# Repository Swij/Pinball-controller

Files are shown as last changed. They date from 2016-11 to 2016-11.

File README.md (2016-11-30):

# Pinball-controller
## Repository structure
* __controller-PCB__ - The kicad PCB design for the controller board.
* __src__ - LUA source code to be run with NodeMcu on the ESP8266.

## Todo
#### PCB-design
* Calculate more precise values for transistor resistors.
* New design for Stern pinball machines.
* Find better solution for I/O shortage on ESP12-E.
* Minified design for factory manufacturing.

#### Firmware
* Make decision on which OS to use on ESP8266. NodeMcu, FreeRTOS, IoTcore etc.
* Communication method/protocol with server.
* Menu traversing method.

#### Master server
* Decide on which language to use. NodeJS, Python, PHP etc.
* Master server locally on for example Raspberry PI or on the internet with a VPS.

#### Payment solution
* Evaluate Swish API.
* Look at other payment solutions such as Strip, Paypal, Braintree etc.
* Decide if we should have an account balance system or only direct payments.

## Ideas
* RFID/NFC reader mounted at the coin machine. Swipe card/tag/phone to pay from balance.

## Kicad dependencies
To view the design in Kicad you need [kicad-ESP8266](https://github.com/jdunmire/kicad-ESP8266) and [Walters kicad libraries](http://smisioto.no-ip.org/elettronica/kicad/kicad-en.htm)

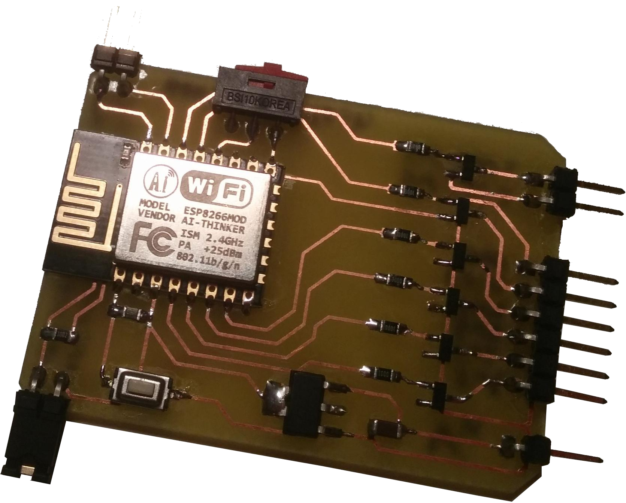
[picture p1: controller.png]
Handmade controller


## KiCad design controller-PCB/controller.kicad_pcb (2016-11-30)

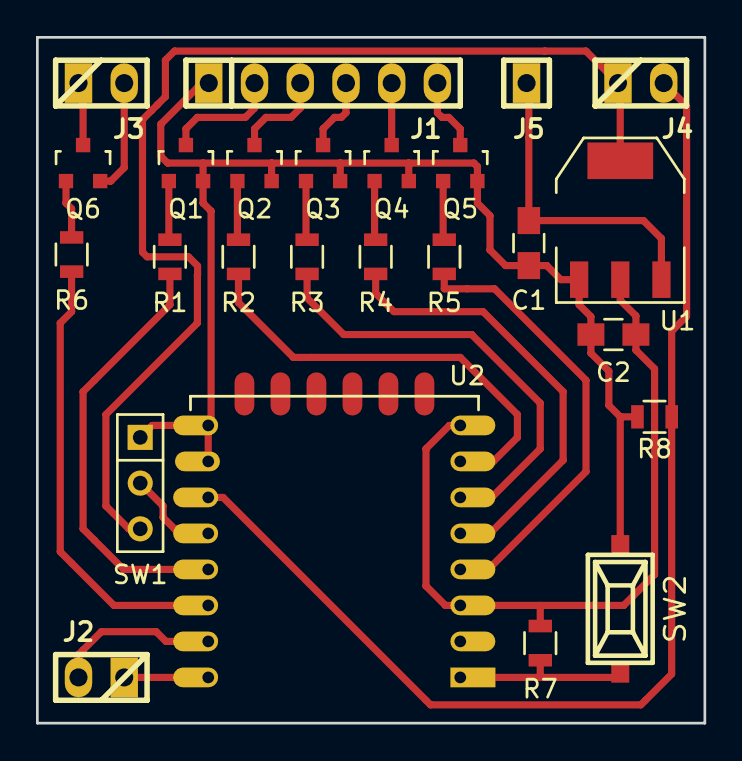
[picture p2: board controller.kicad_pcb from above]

Board: 2 copper layers, 37.1 x 38.1 mm, 25 parts (0 on the bottom side), 27 nets.

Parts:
C1, C2: 10uF; C_0805_HandSoldering
J1: Pinball I/O; pin_strip_6
J2: UART; pin_strip_2
J3: DOOR-IO; pin_strip_2
J4: DOOR-SW; pin_strip_2
J5: 12V; pin_strip_1
Q1, Q2, Q3, Q4, Q5, Q6: NPN_BEC; SOT-23
R1, R2, R3, R4, R5, R6: 1kΩ; R_0805
R7, R8: 10kΩ; R_0805
SW1: FLASH; SW_Micro_SPST
SW2: smd_push
U1: LM1117-3.3; SOT-223
U2: ESP-12E

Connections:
+12V: C1.1, J5.1, U1.3
/COIN: J1.2, Q1.3
/Pinball-SW1: J1.6, Q5.3
/Pinball-SW2: J1.5, Q4.3
/Pinball-SW3: J1.4, Q3.3
/Pinball-SW4: J1.3, Q2.3
/RXD: J2.2, U2.21
/TXD: J2.1, U2.22
DOOR-SW: J4.2, R8.1, U2.17
FLASH: SW1.2, U2.18
GND: C1.2, C2.2, J1.1, Q1.2, Q2.2, Q3.2, Q4.2, Q5.2, R8.2, SW1.1, SW2.2, U1.1, U2.15, U2.16
unnamed: J3.1, Q6.3
unnamed: J3.2, Q6.2
unnamed: Q1.1, R1.1
unnamed: Q2.1, R2.1
unnamed: Q3.1, R3.1
unnamed: Q4.1, R4.1
unnamed: Q5.1, R5.1
unnamed: Q6.1, R6.1
unnamed: R1.2, U2.19
unnamed: R2.2, U2.7
unnamed: R3.2, U2.6
unnamed: R4.2, U2.5
unnamed: R5.2, U2.4
unnamed: R6.2, U2.20
unnamed: R7.2, SW2.1, U2.1
VCC: C2.1, J4.1, R7.1, SW1.3, U1.2, U1.4, U2.3, U2.8

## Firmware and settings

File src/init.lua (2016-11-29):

--[[
GPIO0  = 3
GPIO2  = 4 = ESP-LED
GPIO16 = 8 = ORG-BRN = J205-1  = J1-8  = COIN 1 (LEFT)
GPIO14 = 5 = ORG-RED = J205-2  = J1-7  = COIN 2 (CENTER)
             ORG-BLK = J205-3  = J1-6  = COIN 3 (RIGHT)
             ORG-YEL = J205-4  = J1-5  = COIN 4
                  NC = J205-5
GPIO12 = 6 = ORG-GRN = J205-6  = J1-4  = DIG. SW1 = Escape/Credit
GPIO13 = 7 = ORG-BLU = J205-7  = J1-3  = DIG. SW2 = Left/Vol-
GPIO4  = 2 = ORG-VIO = J205-8  = J1-2  = DIG. SW3 = Right/Vol+
GPIO5  = 1 = ORG-GRY = J205-9  = J1-1  = DIG. SW4 = Enter/Begin Test
                 BLK = J205-10 = J1-10 = GND
                 KEY = J205-11
             ORG-WHT = J205-12 = J1-11 = ENABLE = Enable coin door
--]]

-- Config
local blinkval = gpio.LOW
local pins = {1, 2, 4, 8, 5, 6, 7}

-- Initialise the pin
for n = 1, table.getn(pins) do
    gpio.mode(pins[n], gpio.OUTPUT)
    gpio.write(pins[n], gpio.LOW)
end

-- Pulls a pin low after being high
function releasePin ()
    gpio.write(6, gpio.LOW)
end

-- Pulls a pin high for a set duration
function pushPin ()
    gpio.write(6, gpio.HIGH)
    tmr.alarm(2, 1000, tmr.ALARM_SINGLE, releasePin)
end

-- Blinks LED on ESP
function blinky ()
    gpio.write(4, blinkval)

    if blinkval == gpio.LOW then
        blinkval = gpio.HIGH
    else
        blinkval = gpio.LOW
    end
end

-- LED blink task
tmr.alarm(0, 500, tmr.ALARM_AUTO, blinky)
-- Button pusher task
tmr.alarm(1, 5000, tmr.ALARM_AUTO, pushPin)

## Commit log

2016-11-27 Added PCB files and .gitignore
    [controller.kicad_pcb, controller.sch]
2016-11-29 Made the PCB design tighter and single layer
    [controller-handmade.kicad_pcb, controller.kicad_pcb, controller.sch]
2016-11-30 Made some minor changes to the PCB design and schematic.
    [controller.kicad_pcb, controller.sch]
2016-11-30 Corrected the values of the regulator capacitors and added one on the output.
    [controller.kicad_pcb, controller.sch]
